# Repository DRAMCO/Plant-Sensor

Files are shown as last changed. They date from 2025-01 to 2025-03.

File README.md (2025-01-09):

# Plant Sensor

<p align="center">

</p>

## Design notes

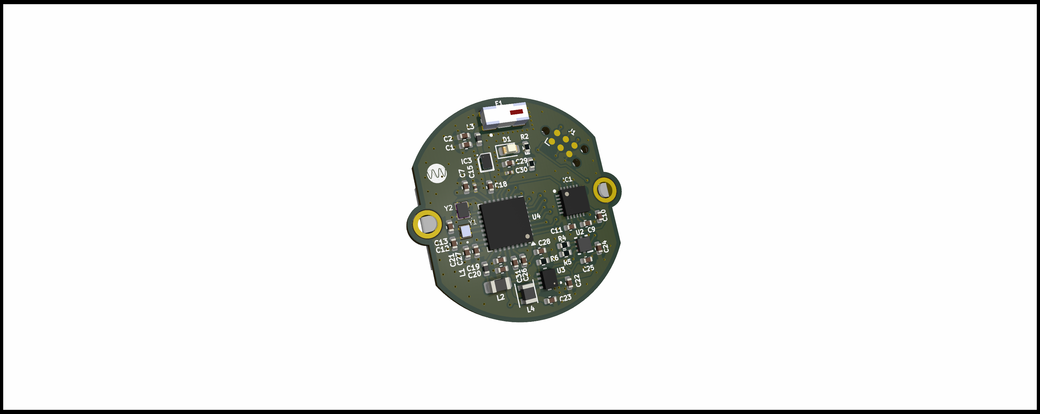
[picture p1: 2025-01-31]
V2/Hardware/Renders/plant_sensor_v2_front.png

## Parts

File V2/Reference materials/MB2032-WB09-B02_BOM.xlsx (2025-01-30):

 |  |  | Bill of materials
 |  |  | Board reference: | MB2032
 |  |  | Variant: | WB09
 |  |  | PCB revision: | B
 |  |  | Assembly revision: | 02
 |  |  | Date: | 6/21/2024
Designator | Description | Package | Manufacturer | Manufacturer_Part_Number | Fitted | Quantity
C2 | Capacitor, MLCC, 0.9pF, 50V, COG, +/-0.05pF, 0402, T=0.5mm | 0402 | MURATA | GJM1555C1HR90WB01 | Fitted | 1
C3, C6, C11, C12 | Capacitor, MLCC, 100nF, ±10%, X7R, 25V, 0402, T=0.5mm | 0402 | MURATA | GRM155R71E104KE14D | Fitted | 4
C4, C5 | Capacitor, C0G, 3 pF, 50V, NPO, ±0.1pF, 0402, T=0.5mm | 0402 | WALSIN TECHNOLOGY CORPORATION | 0402N3R0B500CT | Fitted | 2
C7 | Capacitor, MLCC, 20pF, 25V, COG, +/-2%, 0201, T=0.33mm | 0201 | MURATA | GJM0335C1E200GB01 | Fitted | 1
C8, C9 | Capacitor, MLCC, 10pF, 50V, NPO, +/-5%, 0402, T=0.5mm | 0402 | YAGEO | CC0402JRNPO9BN100 | Fitted | 2
C13 | Capacitor, MLCC, 1uF, X7R, 6.3V, 0402, ± 10%, T=0.5mm | 0402 | MURATA | GRM155R70J105KA12 | Fitted | 1
C14, C15 | Capacitor, MLCC, 4.7uF, X5R, 10 V, 0402, ± 20%, T=0.5mm | 0402 | MURATA | GRM155R61A475MEAAD | Fitted | 2
C16 | Capacitor, MLCC, 0.22uF, X5R, 6.3V, +/-10%, 0402, T=0.5mm | 0402 | YAGEO | CC0402KRX5R5BB224 | Fitted | 1
CN1, CN2 | Header, 25x2, 12.7mm, VR, SMD, T=4.83mm |  | SAMTEC | FTSH-125-02-L-DV | Fitted | 2
HW1 | RFI shield can, 20x15x3mm | 20x15x3mm | HARWIN | S02-20150300 | Fitted | 1
JP1 | Header, 3x1, 2.54mm, VR, TH, T=5.84mm/2.54mm |  | SAMTEC | TSW-103-07-F-S | Fitted | 1
L2 | Inductor, MLCC, 22nH, ±2%, 350mA, 0.58R, 0402, T=1.45mm | 0402 | MURATA | LQG15HN22NG02D | Fitted | 1
L3 | Inductor, MLCC, 10uH, ±20%, 300mA, 845mR, 0805, T=1.45mm | 0805 | MURATA | LQM21DN100M70L | Fitted | 1
R1, R10 | Resistor, 0R, 0402, +/-5%, 1/16W | 0402 | YAGEO | RC0402JR-070RL | Fitted | 2
R3 | Resistor, 100K, 0402, +/-1%, 1/16W | 0402 | YAGEO | RC0402FR-07100KL | Fitted | 1
SB6, SB7, SB9, SB11, SB14, SB16, SB17, SB20, SB28, SB32, SB34, SB37, SB38, SB41, SB43, SB47, SB48, SB55, SB57 | Solder Bridge 0402 ON | 0402 | YAGEO | RC0402JR-070RL | Fitted | 19
SC1, SC2, SC7, SC8 | shield clip Harwin S0981-46R to fix RF shielded cavity - SMT RFI Shield Clip, Corner (T+R) | 0.8x4.7x1.4mm | HARWIN | S0981-46R | Fitted | 4
SC3, SC4, SC5, SC6 | shield clip Harwin S0951-46R to fix RF shielded cavity | 1.1x3.9mm | HARWIN | S0951-46R | Fitted | 4
U1 | Bluetooth® Low Energy wireless SoC | QFN32 | STMICROELECTRONICS | STM32WB09KEV6TR | Fitted | 1
U2 | 2.4 GHz low pass filter matched to BLUENRG-LP-LPS | CSP6 | STMICROELECTRONICS | MLPF-NRG-01D3 | Fitted | 1
X1 | Crystal, 32MHz, 8pF, +/-10ppm, 60R, 2x1.6mm | 2x1.6mm | NDK | NX2016SA-32MHZ-EXS00A-CS06654 | Fitted | 1
X2 | Crystal, 32.768kHz, 7pF, +/-20ppm, 80K, 2.05x1.2mm | 2.05x1.2mm | NDK | NX2012SA-32.768KHZ-EXS00A-MU00389 | Fitted | 1
C1 | Capacitor, MLCC, 6.8pF, 50V, C0G, +/-0.05pF, 0402, T=0.5mm | 0402 | MURATA | GJM1555C1H6R8WB01 | Not Fitted | 0
C10 | Capacitor, MLCC, 100nF, ±10%, X7R, 25V, 0402, T=0.5mm | 0402 | MURATA | GRM155R71E104KE14D | Not Fitted | 0
CN3 | Header, 7x2, 1.27mm, VR, T=5.97mm, FTSH series STDC14 without Alignment Pin |  | SAMTEC | FTSH-107-01-L-DV-K | Not Fitted | 0
CN4 | Connector_RF, 0Hz to 6GHz, 50R, VR, SMD, T= 1.25mm |  | HIROSE | U.FL-R-SMT-1 | Not Fitted | 0
R2 | Resistor, 0R, 0402, +/-5%, 1/16W | 0402 | YAGEO | RC0402JR-070RL | Not Fitted | 0
R4, R5, R6, R7, R8 | Resistor, 47R, 0402, +/-1%, 1/16W | 0402 | YAGEO | RC0402FR-0747RL | Not Fitted | 0
R9 | Resistor, 100R, 0402, +/- 1%, 1/16W | 0402 | YAGEO | RC0402FR-07100RL | Not Fitted | 0
SB1, SB2, SB3, SB4, SB5, SB8, SB10, SB12, SB13, SB15, SB18, SB19, SB21, SB22, SB23, SB24, SB25, SB29, SB30, SB31, SB33, SB35, SB36, SB39, SB40, SB42, SB44, SB45, SB46, SB49, SB51, SB52, SB53, SB54, SB56 | Solder Bridge 0402 ON | 0402 | YAGEO | RC0402JR-070RL | Not Fitted | 0

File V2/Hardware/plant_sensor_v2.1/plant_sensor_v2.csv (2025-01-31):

Id | Designator | Footprint | Quantity | Designation | Supplier and ref
1 | C23 | C_0402_1005Metric | 1 | 10u
2 | J1 | Tag-Connect_TC2030-IDC-NL_2x03_P1.27mm_Vertical | 1 | TC2030_SWD-MCP-NL
3 | E1 | XDCR_2450AT42E0100E | 1 | 609-2450AT42E0100001
4 | C27,C25,C24,C9,C10,C7,C19,C26,C11,C29 | C_0402_1005Metric | 10 | 100n
5 | C31 | C_0402_1005Metric | 1 | 220n
6 | C1,C2 | C_0402_1005Metric | 2 | DNP
7 | U2 | RSE0008A | 1 | TPS22960RSER
8 | C21,C20,C22 | C_0402_1005Metric | 3 | 4.7u
9 | D1 | LED_0603_1608Metric | 1 | LED, RED
10 | L3 | L_0402_1005Metric | 1 | DNP
11 | TP10,TP1,TP8,TP2,TP4,TP5,TP11,TP9,TP6,TP7 | TestPoint_Pad_D1.0mm | 10 | TestPoint
12 | L2 | L_0805_2012Metric | 1 | LQM21DN100M70L - 10u
13 | C28 | C_0402_1005Metric | 1 | 1u
14 | R4 | R_0402_1005Metric | 1 | 470k
15 | U3 | VSON8_2P1X1P6_TEX | 1 | TPS62840DLCR
16 | R6 | R_0402_1005Metric | 1 | 0
17 | L4 | L_Murata_DFE201610P | 1 | 81-DFE201612E-2R2MP2 - 2u2
18 | R2 | R_0402_1005Metric | 1 | R
19 | Y1 | XTAL_ECS-.327-6-1210-TR | 1 | 520-.327-6-1210-TR (32.768kHz)
20 | C15,C30 | C_0201_0603Metric | 2 | 3p
21 | L1 | L_0402_1005Metric | 1 | LQG15HN22NG02D - 22n
22 | Y2 | OSCSC105P160X120X35-4N | 1 | NX1612SA-32.000MHZ-CHP-CIS-3
23 | IC1 | ICM20948 | 1 | ICM-20948
24 | C12,C13 | C_0402_1005Metric | 2 | 6p
25 | C18 | C_0402_1005Metric | 1 | 20p
26 | R5 | R_0402_1005Metric | 1 | 220k
27 | R3 | R_0402_1005Metric | 1 | 100k
28 | IC3 | MLPFNRG01D3 | 1 | MLPF-NRG-01D3
29 | U4 | QFN-32-1EP_5x5mm_P0.5mm_EP3.7x3.7mm | 1 | STM32WB09KEVx
30 | B1 | WA-BCMC_79523211 | 1 | WA-BCMC

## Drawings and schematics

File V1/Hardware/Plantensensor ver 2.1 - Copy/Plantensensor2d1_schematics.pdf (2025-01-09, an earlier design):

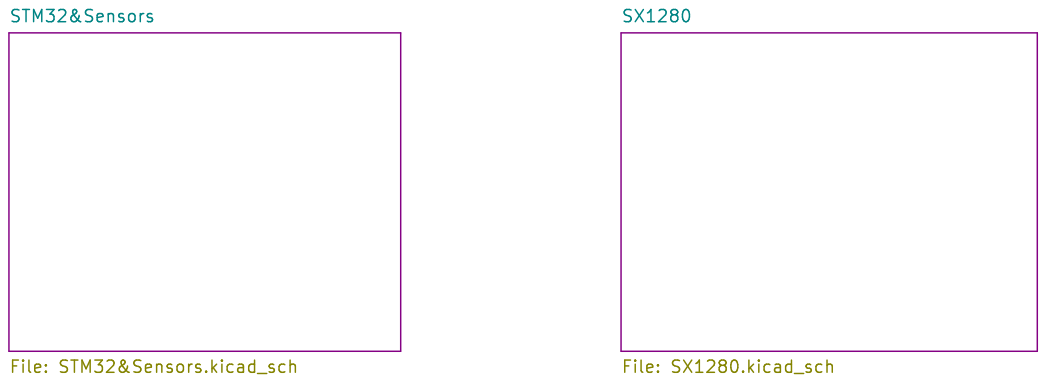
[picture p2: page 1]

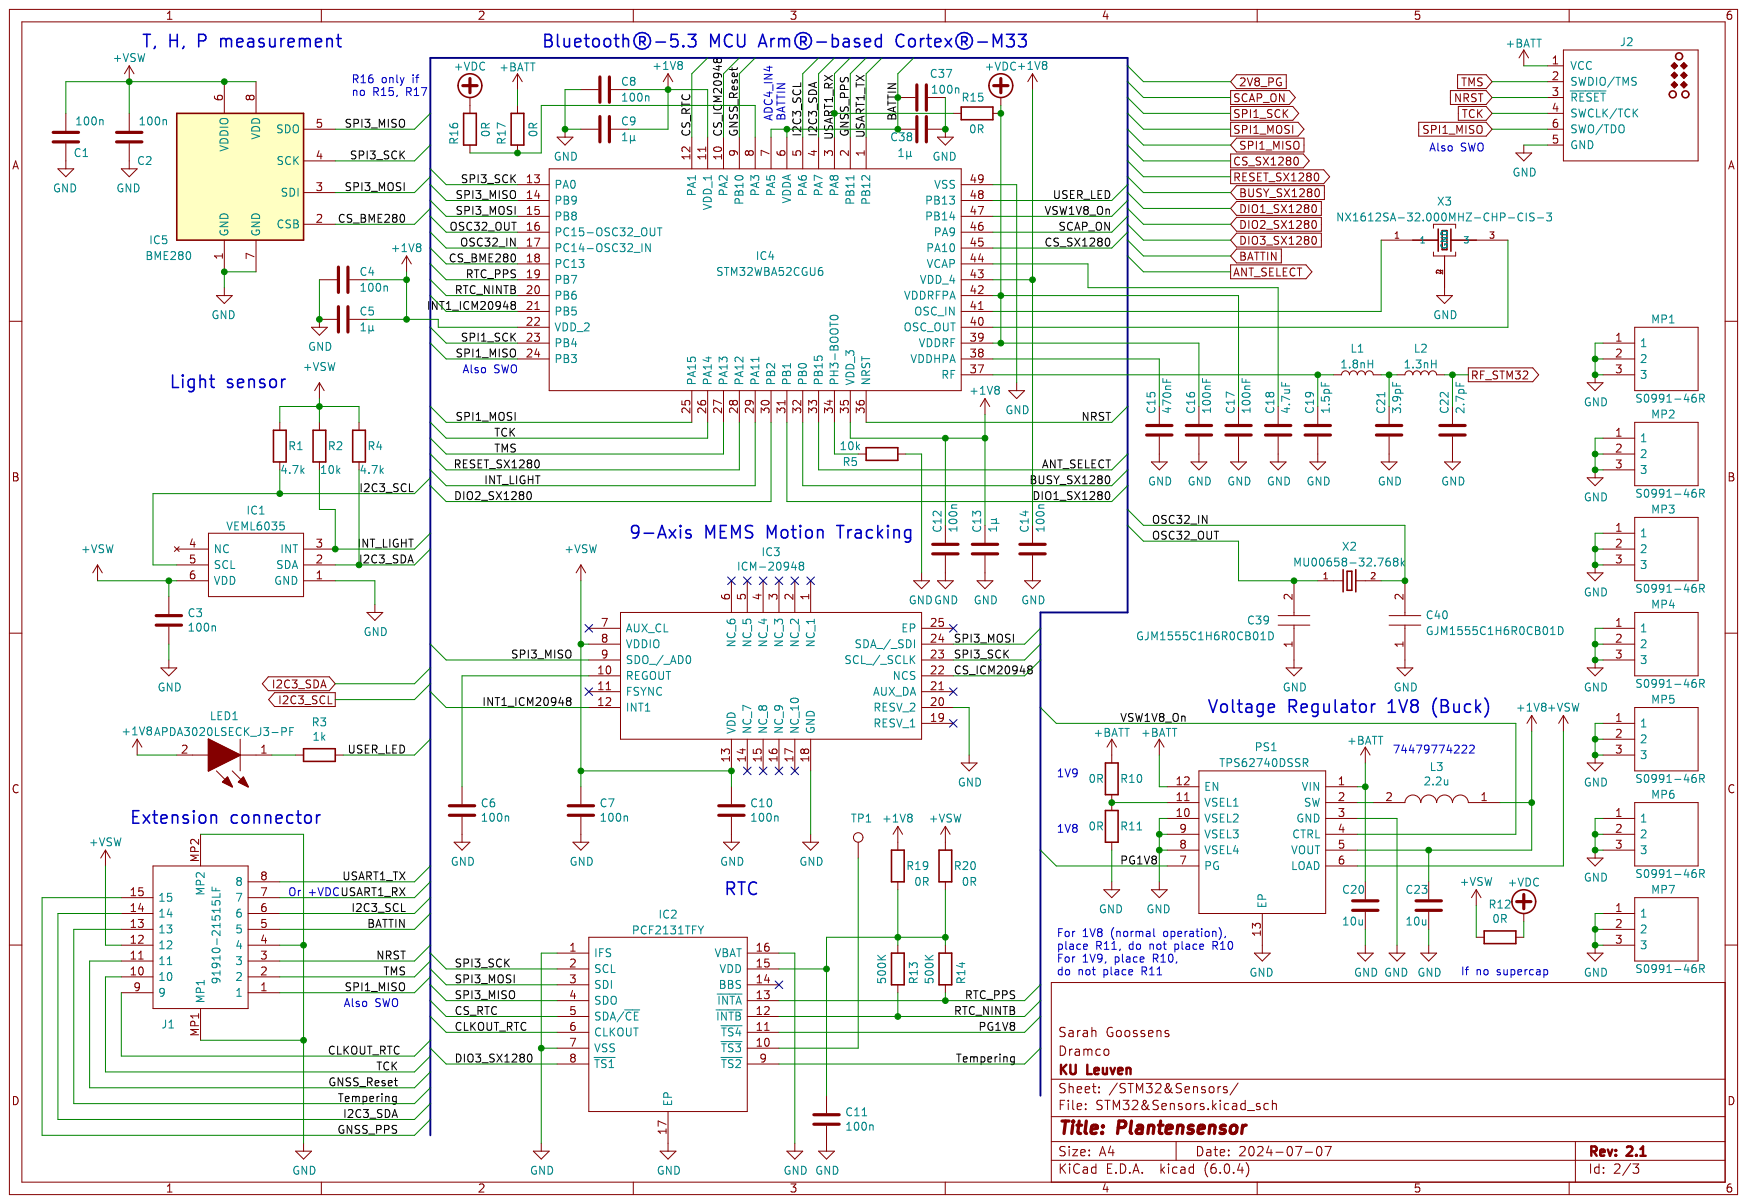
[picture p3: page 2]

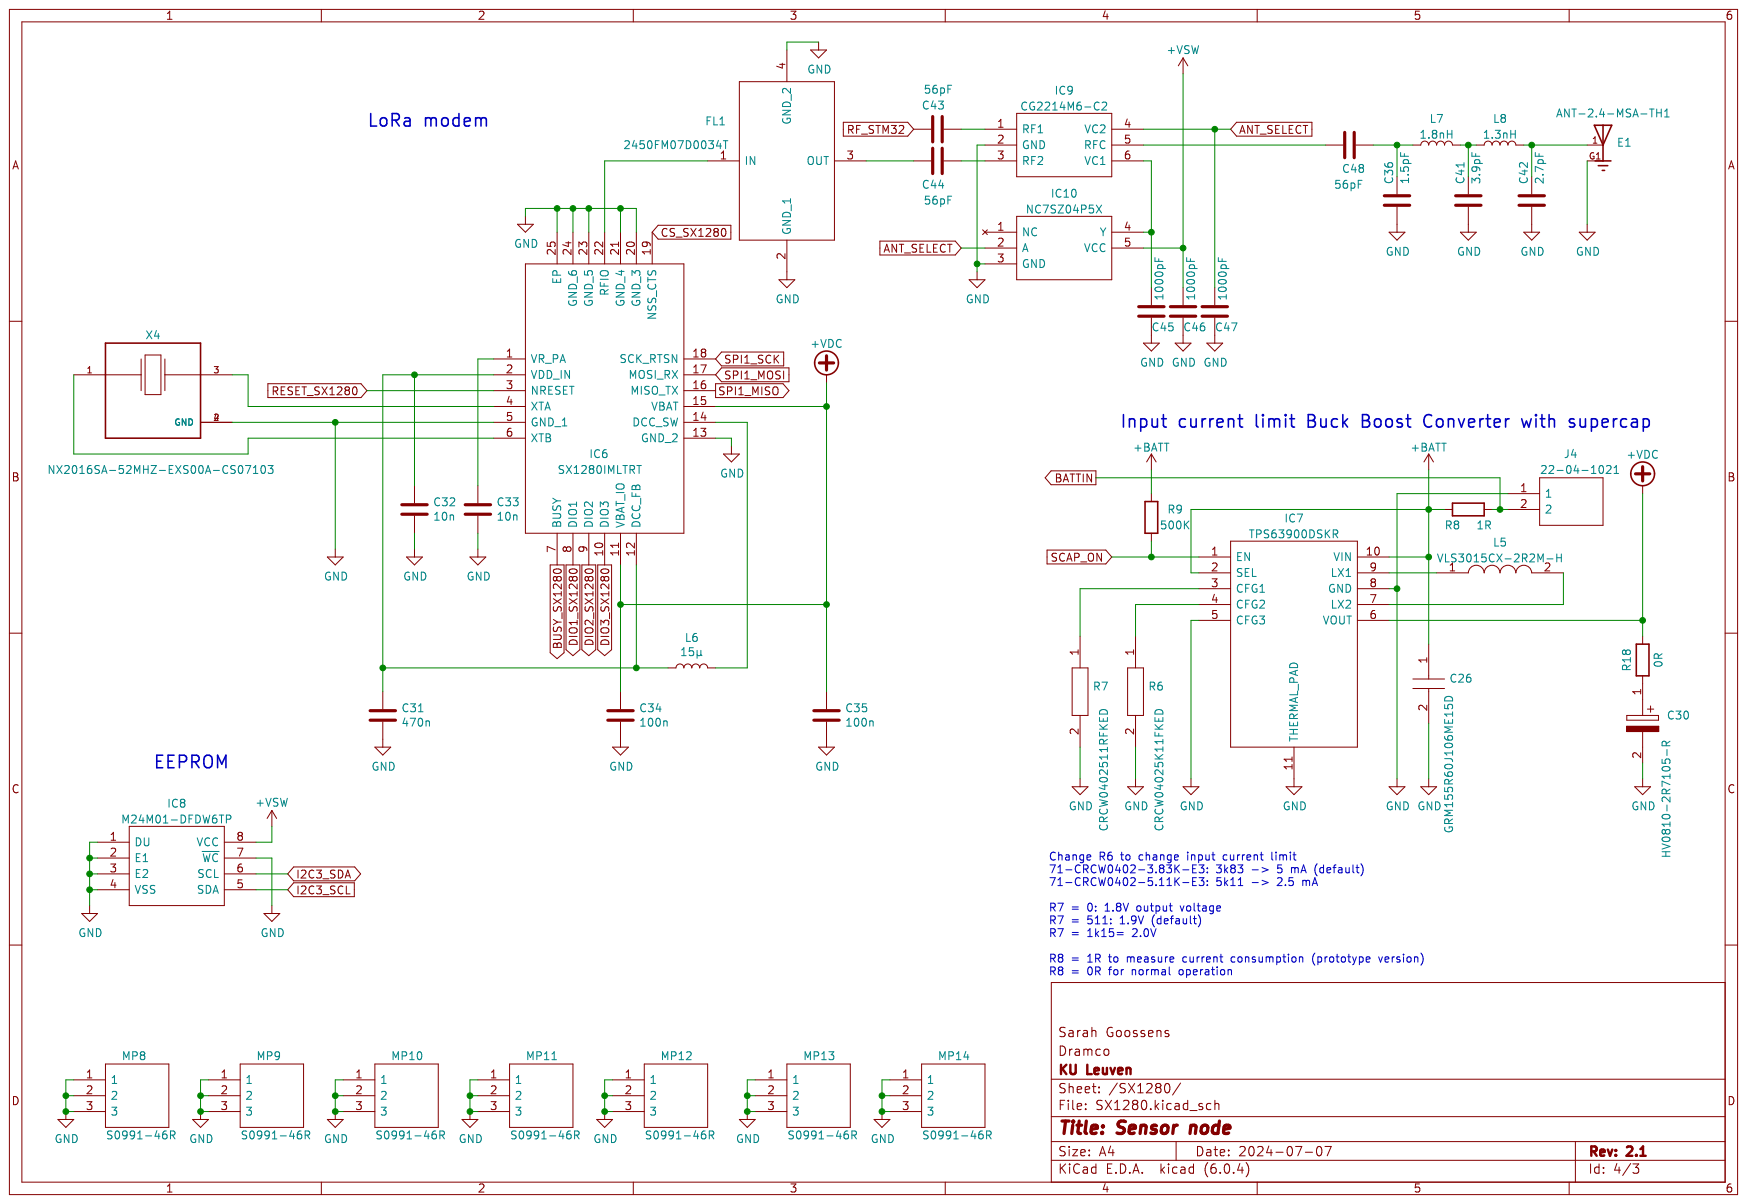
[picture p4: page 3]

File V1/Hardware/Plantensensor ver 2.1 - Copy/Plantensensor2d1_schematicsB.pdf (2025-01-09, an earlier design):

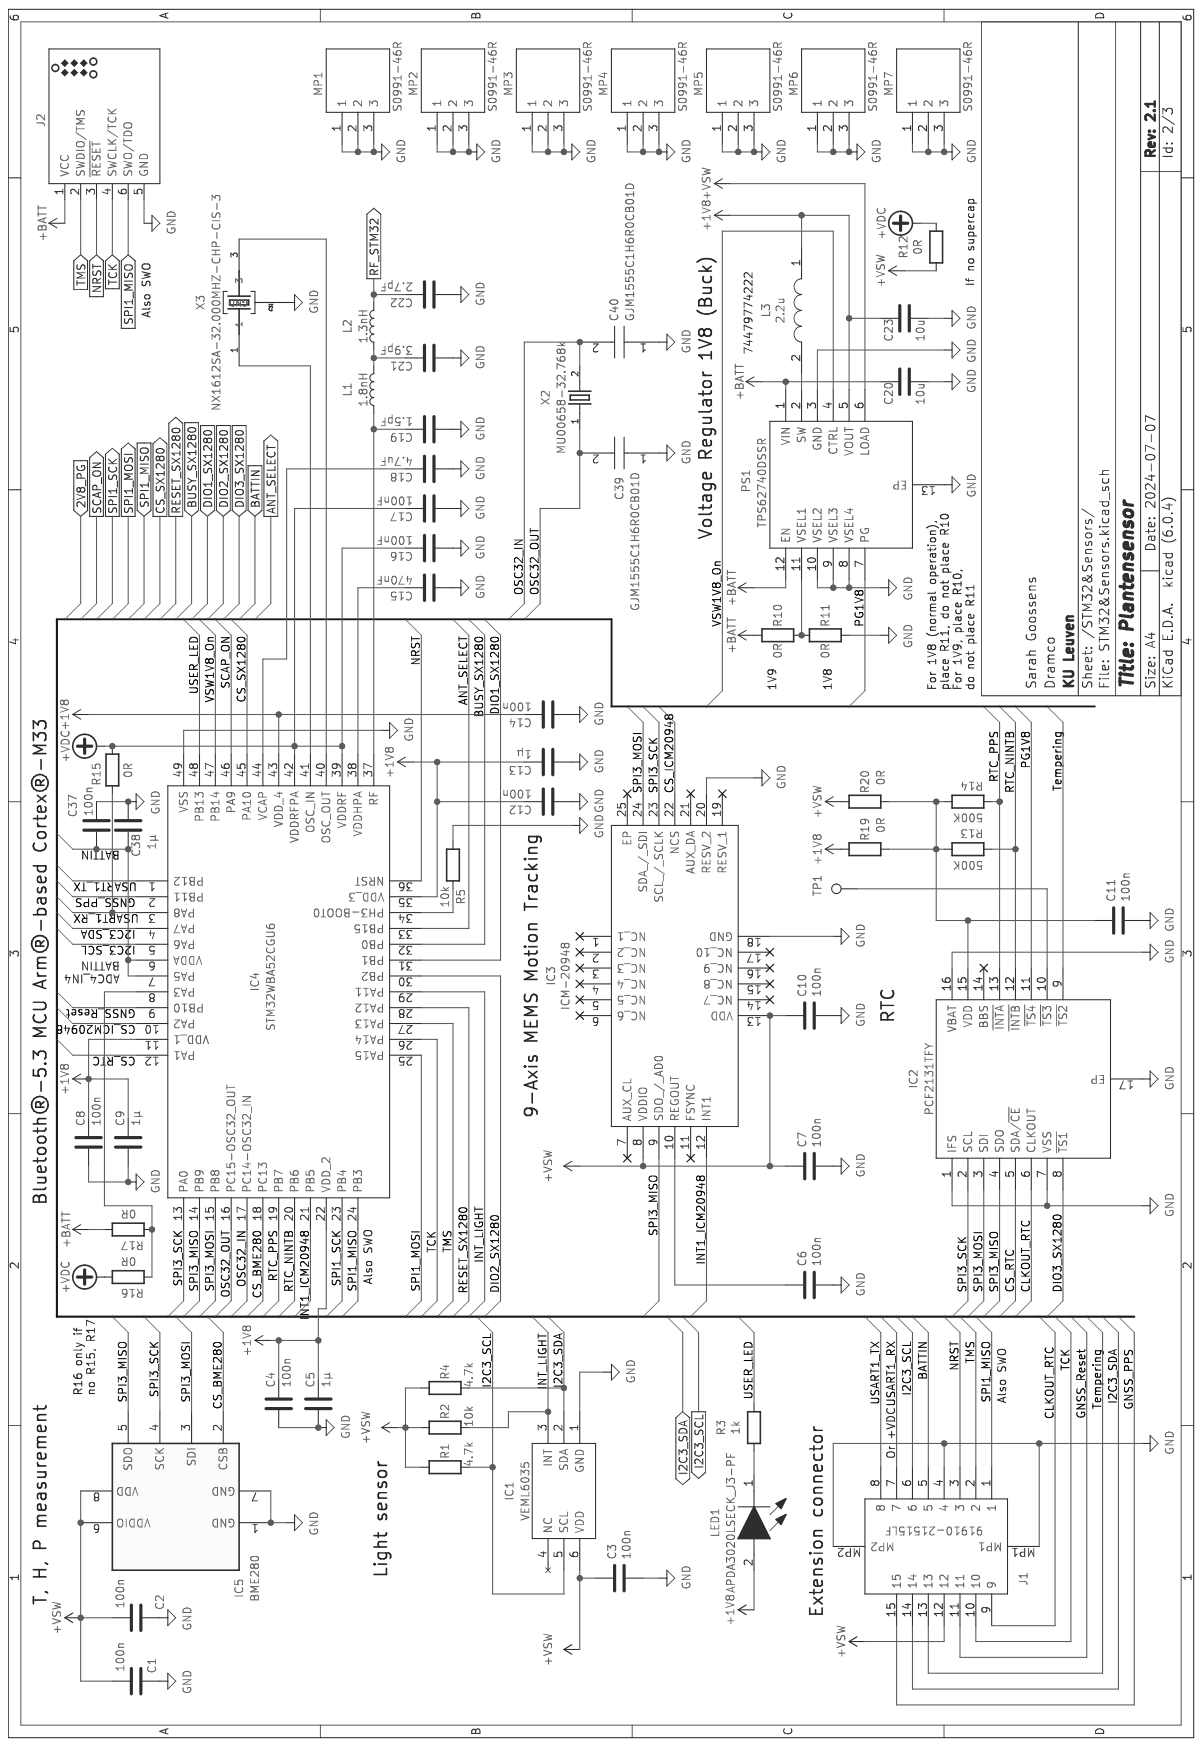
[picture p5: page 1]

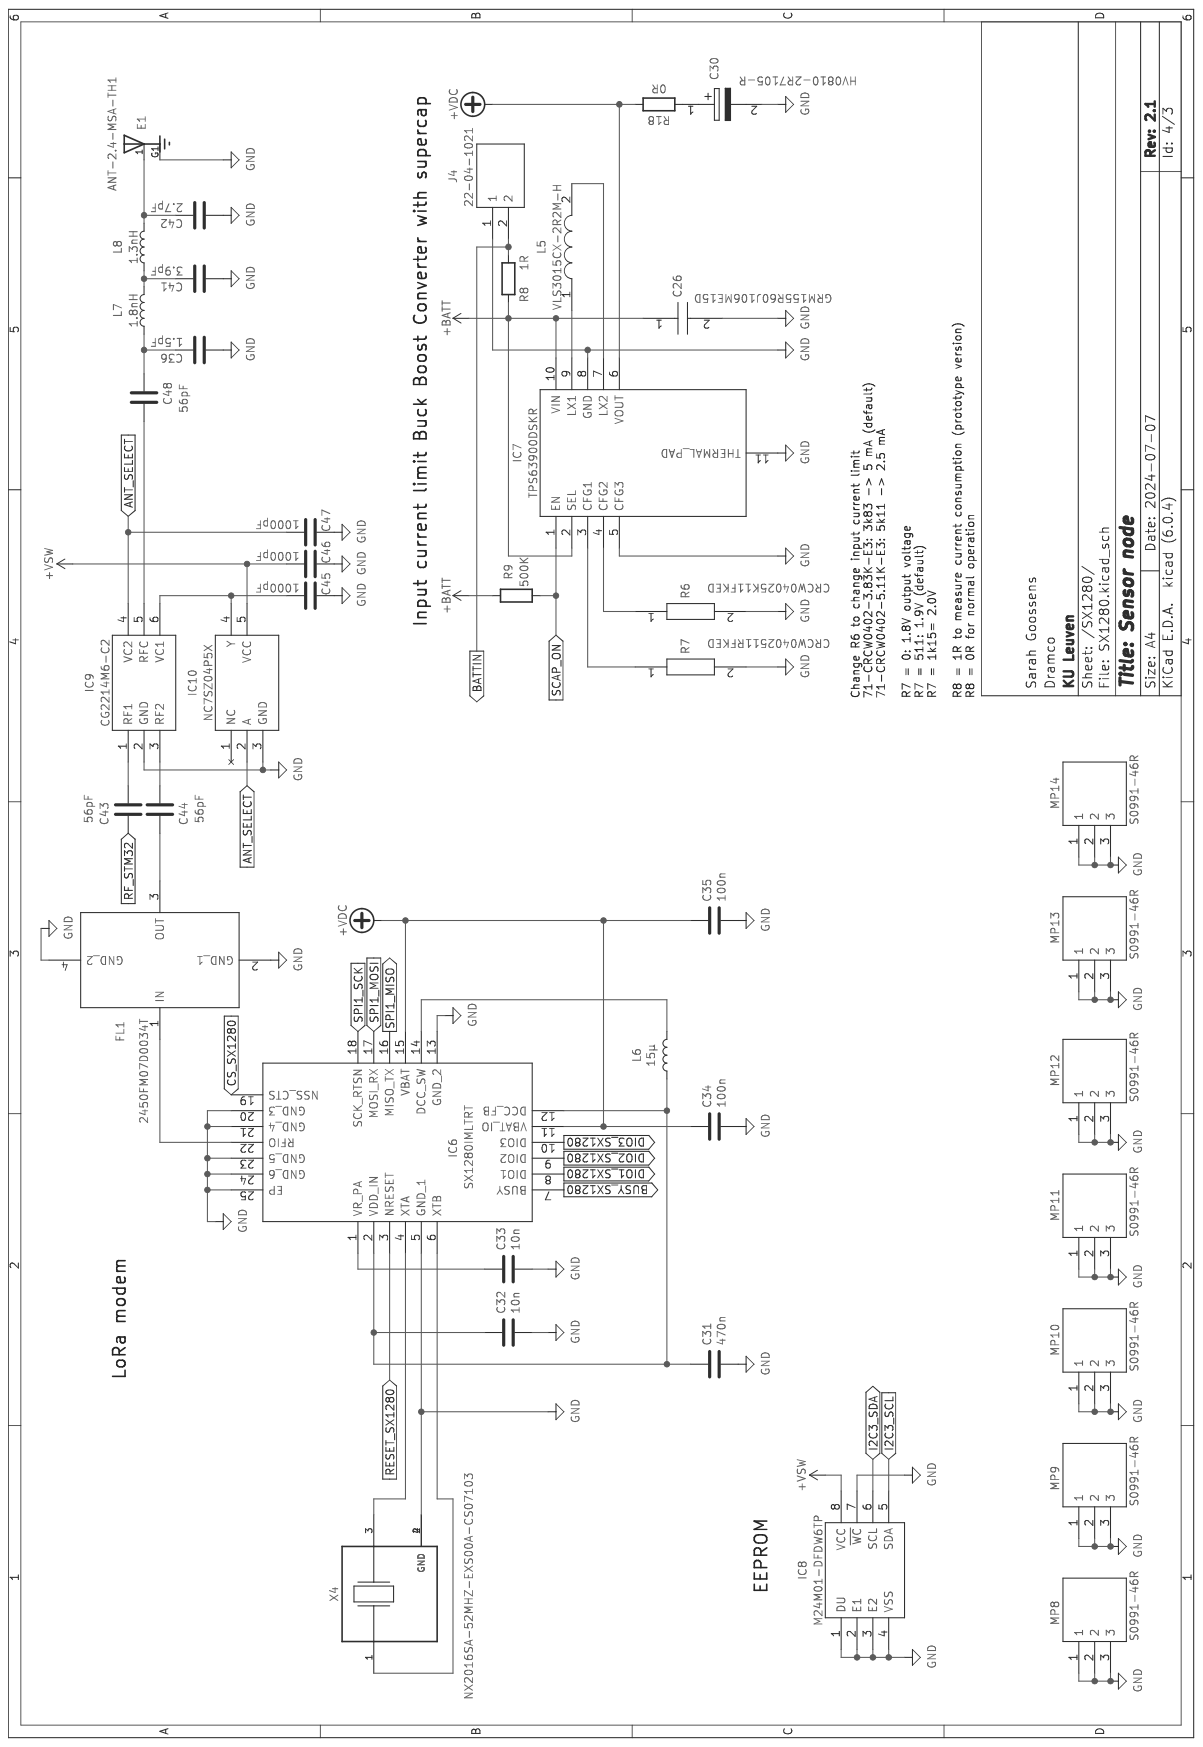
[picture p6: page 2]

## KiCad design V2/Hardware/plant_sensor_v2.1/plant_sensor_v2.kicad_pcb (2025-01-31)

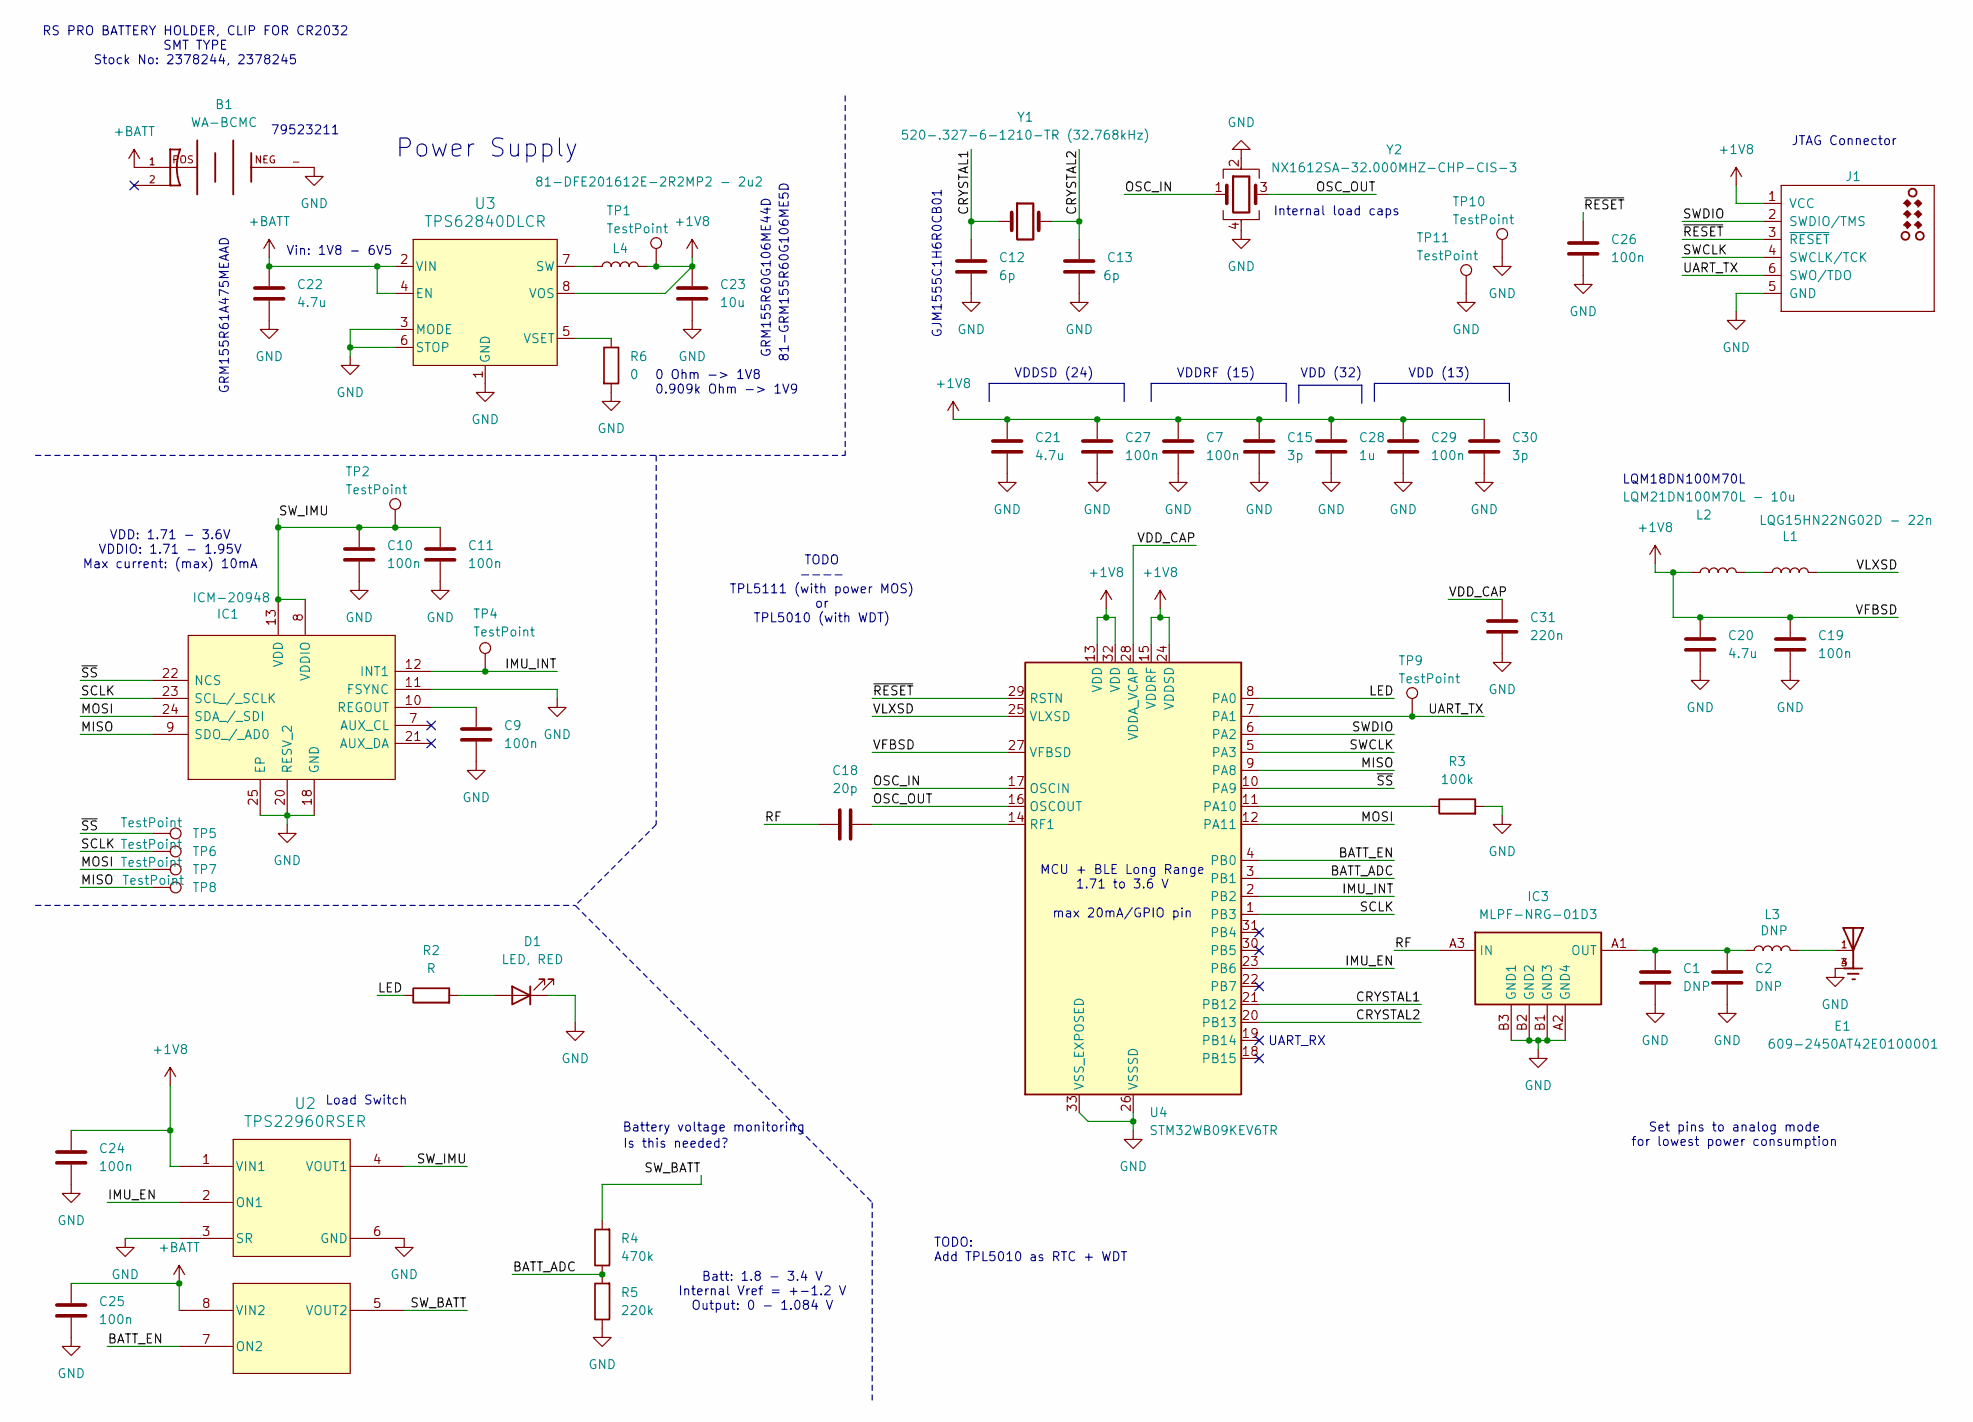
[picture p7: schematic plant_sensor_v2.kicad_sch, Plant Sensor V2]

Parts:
B1: WA-BCMC; WA-BCMC_79523211; PART-NUMBER 79523141
C1, C2: DNP; C_0402_1005Metric
C7, C9, C10, C11, C19, C24, C25, C26, C27, C29: 100n; C_0402_1005Metric
C12, C13: 6p; C_0402_1005Metric
C15, C30: 3p; C_0201_0603Metric
C18: 20p; C_0402_1005Metric
C20, C21, C22: 4.7u; C_0402_1005Metric
C23: 10u; C_0402_1005Metric
C28: 1u; C_0402_1005Metric
C31: 220n; C_0402_1005Metric
D1: LED, RED; LED_0603_1608Metric
E1: 609-2450AT42E0100001; XDCR_2450AT42E0100E; PARTREV 1.3
IC1: ICM-20948; ICM20948; Mouser Part Number 410-ICM-20948
IC3: MLPF-NRG-01D3; MLPFNRG01D3; Mouser Part Number 511-MLPF-NRG-01D3
J1: TC2030_SWD-MCP-NL; Tag-Connect_TC2030-IDC-NL_2x03_P1.27mm_Vertical
L1: LQG15HN22NG02D - 22n; L_0402_1005Metric
L2: LQM21DN100M70L - 10u; L_0805_2012Metric
L3: DNP; L_0402_1005Metric
L4: 81-DFE201612E-2R2MP2 - 2u2; L_Murata_DFE201610P
R2: R; R_0402_1005Metric
R3: 100k; R_0402_1005Metric
R4: 470k; R_0402_1005Metric
R5: 220k; R_0402_1005Metric
R6: 0; R_0402_1005Metric
TP1, TP2, TP4, TP5, TP6, TP7, TP8, TP9, TP10, TP11: TestPoint; TestPoint_Pad_D1.0mm
U2: TPS22960RSER; RSE0008A
U3: TPS62840DLCR; VSON8_2P1X1P6_TEX
U4: STM32WB09KEV6TR; QFN-32-1EP_5x5mm_P0.5mm_EP3.7x3.7mm
Y1: 520-.327-6-1210-TR (32.768kHz); XTAL_ECS-.327-6-1210-TR
Y2: NX1612SA-32.000MHZ-CHP-CIS-3; OSCSC105P160X120X35-4N

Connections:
+1V8: C7.1, C15.1, C19.1, C20.1, C21.1, C23.1, C24.1, C27.1, C28.1, C29.1, C30.1, J1.1 (VCC), L2.1, L4.2, TP1.1, U2.1 (VIN1), U3.8 (VOS), U4.13 (VDD), U4.15 (VDDRF), U4.24 (VDDSD), U4.27 (VFBSD), U4.32 (VDD)
+BATT: B1.1, C22.1, C25.1, U2.8 (VIN2), U3.2 (VIN), U3.4 (EN)
/BATT_ADC: R4.1, R5.2, U4.3 (PB1)
/BATT_EN: U2.7 (ON2), U4.4 (PB0)
/CRYSTAL1: C12.1, U4.21 (PB12), Y1.1
/CRYSTAL2: C13.1, U4.20 (PB13), Y1.2
/IMU_EN: U2.2 (ON1), U4.23 (PB6)
/IMU_INT: IC1.12 (INT1), TP4.1, U4.2 (PB2)
/LED: R2.1, U4.8 (PA0)
/MISO: IC1.9 (SDO_/_AD0), TP8.1, U4.9 (PA8)
/MOSI: IC1.24 (SDA_/_SDI), TP7.1, U4.12 (PA11)
/OSC_IN: U4.17 (OSCIN), Y2.1
/OSC_OUT: U4.16 (OSCOUT), Y2.3
/RF: C18.1, IC3.A3 (IN)
/SCLK: IC1.23 (SCL_/_SCLK), TP6.1, U4.1 (PB3)
/SWCLK: J1.4 (SWCLK/TCK), U4.5 (PA3)
/SWDIO: J1.2 (SWDIO/TMS), U4.6 (PA2)
/SW_BATT: R4.2, U2.5 (VOUT2)
/SW_IMU: C10.1, C11.1, IC1.8 (VDDIO), IC1.13 (VDD), TP2.1, U2.4 (VOUT1)
/UART_TX: J1.6 (SWO/TDO), TP9.1, U4.7 (PA1)
/VDD_CAP: C31.1, U4.28 (VDDA_VCAP)
/VLXSD: L1.2, U4.25 (VLXSD)
/~RESET: C26.2, J1.3 (~RESET), U4.29 (RSTN)
/~SS: IC1.22 (NCS), TP5.1, U4.10 (PA9)
GND: B1.-, C1.2, C2.2, C7.2, C9.2, C10.2, C11.2, C12.2, C13.2, C15.2, C19.2, C20.2, C21.2, C22.2, C23.2, C24.2, C25.2, C26.1, C27.2, C28.2, C29.2, C30.2, C31.2, D1.1 (K), E1.3, E1.4, IC1.11 (FSYNC), IC1.18 (GND), IC1.20 (RESV_2), IC1.25 (EP), IC3.A2 (GND4), IC3.B1 (GND3), IC3.B2 (GND2), IC3.B3 (GND1), J1.5 (GND), R3.2, R5.1, R6.2, TP10.1, TP11.1, U2.3 (SR), U2.6 (GND), U3.1 (GND), U3.3 (MODE), U3.6 (STOP), U4.26 (VSSSD), U4.33 (VSS_EXPOSED), Y2.2, Y2.4
unnamed: D1.2 (A), R2.2
unnamed: E1.1, L3.2
unnamed: C9.1, IC1.10 (REGOUT)
unnamed: C1.1, C2.1, IC3.A1 (OUT), L3.1
unnamed: L1.1, L2.2
unnamed: L4.1, U3.7 (SW)
unnamed: R6.1, U3.5 (VSET)
unnamed: R3.1, U4.11 (PA10)
unnamed: C18.2, U4.14 (RF1)

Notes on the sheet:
UART_RX
MCU + BLE Long Range 1.71 to 3.6 V max 20mA/GPIO pin
79523211
Vin: 1V8 - 6V5
Internal load caps
GRM155R60G106ME44D
Power Supply
RS PRO BATTERY HOLDER, CLIP FOR CR2032 SMT TYPE Stock No: 2378244, 2378245
GRM155R61A475MEAAD
VDD (32)
Battery voltage monitoring
JTAG Connector
Load Switch
Is this needed?
LQM18DN100M70L
Set pins to analog mode for lowest power consumption
VDD: 1.71 - 3.6V VDDIO: 1.71 - 1.95V Max current: (max) 10mA
VDD (13)
Batt: 1.8 - 3.4 V Internal Vref = +-1.2 V Output: 0 - 1.084 V
0 Ohm -> 1V8 0.909k Ohm -> 1V9
VDDSD (24)
TODO ---- TPL5111 (with power MOS) or TPL5010 (with WDT)
TODO: Add TPL5010 as RTC + WDT
VDDRF (15)
81-GRM155R60G106ME5D
GJM1555C1H6R0CB01

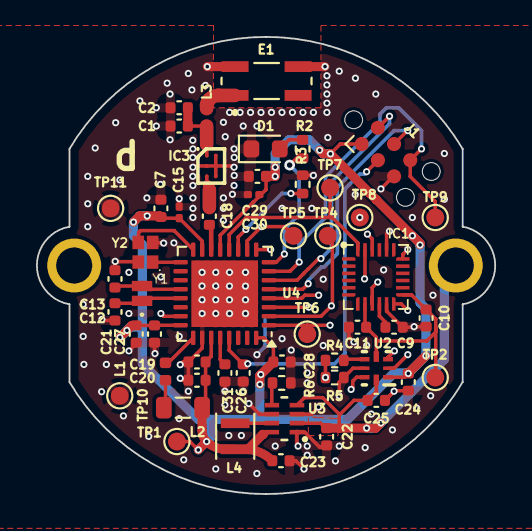
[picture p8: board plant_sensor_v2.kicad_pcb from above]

Board: 4 copper layers, 25.5 x 25.4 mm, 53 parts (1 on the bottom side), 34 nets.

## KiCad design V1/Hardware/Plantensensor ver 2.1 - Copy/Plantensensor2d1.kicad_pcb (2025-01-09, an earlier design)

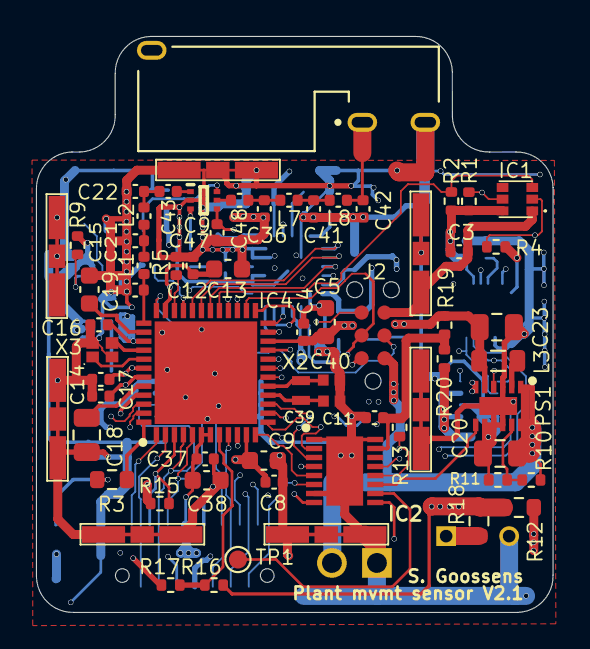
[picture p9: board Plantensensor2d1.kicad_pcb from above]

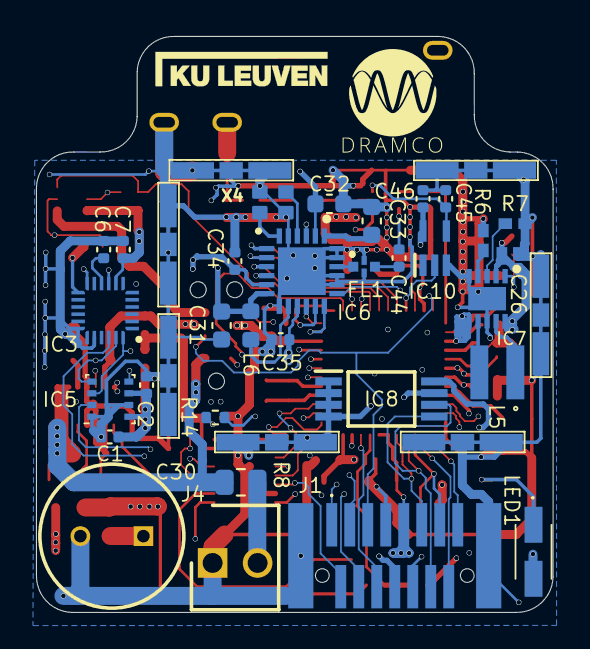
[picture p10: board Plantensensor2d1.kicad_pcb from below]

Board: 4 copper layers, 28.7 x 32.0 mm, 104 parts (38 on the bottom side), 77 nets.

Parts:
C1, C2, C3, C4, C6, C7, C8, C11, C12, C14, C34, C35, C37: 100n; C_0402_1005Metric
C5, C9, C13, C38: 1µ; C_0603_1608Metric
C15: 470nF; C_0603_1608Metric
C16, C17: 100nF; C_0402_1005Metric
C18: 4.7uF; C_0805_2012Metric
C19, C36: 1.5pF; C_0402_1005Metric
C20, C23: 10u; C_0805_2012Metric
C21, C41: 3.9pF; C_0402_1005Metric
C22, C42: 2.7pF; C_0402_1005Metric
C26: GRM155R60J106ME15D; CAPC1005X55N
C30: HV0810-2R7105-R; CAPPRD350W52D800H1350
C31: 470n; C_0603_1608Metric
C32, C33: 10n; C_0603_1608Metric
C39, C40: GJM1555C1H6R0CB01D; CAPC1005X55N
C43, C44, C48: 56pF; C_0402_1005Metric
C45, C46, C47: 1000pF; C_0402_1005Metric
E1: ANT-2.4-MSA-TH1; XCVR_ANT-2.4-MSA-TH1
FL1: 2450FM07D0034T
IC1: VEML6035
IC2: PCF2131TFY; SON50P350X450X150-17N-D_PCF2131TFY
IC3: ICM-20948; QFN40P300X300X105-25N-D_ICM20948
IC4: STM32WBA52CGU6; QFN50P700X700X65-49N-D
IC5: BME280; Bosch_LGA-8_2.5x2.5mm_P0.65mm_ClockwisePinNumbering
IC6: SX1280IMLTRT; QFN50P400X400X100-25N-D_SX1280
IC7: TPS63900DSKR; SON50P250X250X80-11N-D
IC8: M24M01-DFDW6TP; SOP65P640X120-8N
IC9: CG2214M6-C2; SOTFL48P130X55-6N
IC10: NC7SZ04P5X; SOT65P210X110-5N
J1: 91910-21515LF; 9191021515LF
J2: TC2030_SWD-MCP-NL; TC2030-MCP-NL
J4: 22-04-1021; SHDR2W64P0X250_1X2_450X580X1170P
L1, L7: 1.8nH; C_0402_1005Metric
L2, L8: 1.3nH; C_0402_1005Metric
L3: 2.2u; L_0805_2012Metric
L5: VLS3015CX-2R2M-H; VLS3015
L6: 15µ; L_0603_1608Metric
LED1: APDA3020LSECK_J3-PF; APDA3020LSECKJ3PF
MP1, MP2, MP3, MP4, MP5, MP6, MP7, MP8, MP9, MP10, MP11, MP12, MP13, MP14: S0991-46R; S099146R
PS1: TPS62740DSSR; SON50P200X300X80-13N_TPS62740DSSR
R1, R4: 4.7k; R_0402_1005Metric
R2, R5: 10k; R_0402_1005Metric
R3: 1k; R_0603_1608Metric
R6: CRCW04025K11FKED; RESC1005X40N
R7: CRCW0402511RFKED; RESC1005X40N
R8: 1R; R_0805_2012Metric
R9, R13, R14: 500K; R_0402_1005Metric
R10, R11, R15, R16, R17, R19, R20: 0R; R_0402_1005Metric
R12, R18: 0R; R_0603_1608Metric
TP1: TestPoint; TestPoint_Pad_D1.0mm
X2: MU00658-32.768k; XTAL_ECS-.327-12.5-16-TR
X3: NX1612SA-32.000MHZ-CHP-CIS-3; OSCSC105P160X120X35-4N
X4: NX2016SA-52MHZ-EXS00A-CS07103; OSCCC200X160X50N

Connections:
+1V8: C4.1, C5.1, C8.1, C9.1, C12.1, C13.1, C14.1, C23.1, IC4.11 (VDD_1), IC4.22 (VDD_2), IC4.35 (VDD_3), IC4.43 (VDD_4), L3.1, LED1.2, PS1.5 (VOUT), R19.1
+BATT: C20.1, C26.1, IC7.2 (SEL), IC7.10 (VIN), J2.1 (VCC), PS1.1 (VIN), PS1.12 (EN), R8.1, R9.2, R10.1, R17.2
+VDC: C16.1, C17.1, C34.1, C35.1, IC4.39 (VDDRF), IC4.42 (VDDRFPA), IC6.11 (VBAT_IO), IC6.15 (VBAT), IC7.6 (VOUT), R12.2, R15.2, R16.2, R18.2
+VSW: C1.1, C2.1, C3.1, C7.1, C46.2, IC1.6 (VDD), IC3.8 (VDDIO), IC3.13 (VDD), IC5.6 (VDDIO), IC5.8 (VDD), IC8.8 (VCC), IC10.5 (VCC), J1.12, PS1.6 (LOAD), R1.1, R2.1, R4.1, R12.1, R20.1
/STM32&Sensors/CLKOUT_RTC: IC2.6 (CLKOUT), J1.9
/STM32&Sensors/CS_BME280: IC4.18 (PC13), IC5.2 (CSB)
/STM32&Sensors/CS_ICM20948: IC3.22 (NCS), IC4.10 (PA2)
/STM32&Sensors/CS_RTC: IC2.5 (SDA/~CE), IC4.12 (PA1)
/STM32&Sensors/GNSS_PPS: IC4.2 (PB11), J1.15
/STM32&Sensors/GNSS_Reset: IC4.9 (PB10), J1.11
/STM32&Sensors/INT1_ICM20948: IC3.12 (INT1), IC4.21 (PB5)
/STM32&Sensors/INT_LIGHT: IC1.3 (INT), IC4.29 (PA11), R2.2
/STM32&Sensors/OSC32_IN: C40.2, IC4.17 (PC14-OSC32_IN), X2.2
/STM32&Sensors/OSC32_OUT: C39.2, IC4.16 (PC15-OSC32_OUT), X2.1
/STM32&Sensors/PG1V8: IC2.11 (~TS4), PS1.7 (PG)
/STM32&Sensors/RTC_NINTB: IC2.12 (~INTB), IC4.20 (PB6), R13.2
/STM32&Sensors/RTC_PPS: IC2.13 (~INTA), IC4.19 (PB7), R14.2
/STM32&Sensors/SPI3_MISO: IC2.4 (SDO), IC3.9 (SDO_/_AD0), IC4.14 (PB9), IC5.5 (SDO)
/STM32&Sensors/SPI3_MOSI: IC2.3 (SDI), IC3.24 (SDA_/_SDI), IC4.15 (PB8), IC5.3 (SDI)
/STM32&Sensors/SPI3_SCK: IC2.2 (SCL), IC3.23 (SCL_/_SCLK), IC4.13 (PA0), IC5.4 (SCK)
/STM32&Sensors/Tempering: IC2.9 (~TS2), J1.13
/STM32&Sensors/USART1_RX: IC4.3 (PA8), J1.7, R15.1
/STM32&Sensors/USART1_TX: IC4.1 (PB12), J1.8
/STM32&Sensors/USER_LED: IC4.48 (PB13), R3.2
/STM32&Sensors/VSW1V8_On: IC4.47 (PB14), PS1.4 (CTRL)
ANT_SELECT: C47.2, IC4.33 (PB15), IC9.4 (VC2), IC10.2 (A)
BATTIN: C37.1, C38.1, IC4.6 (VDDA), IC4.7 (PA5), J1.5, J4.2, R8.2
BUSY_SX1280: IC4.32 (PB0), IC6.7 (BUSY)
CS_SX1280: IC4.45 (PA10), IC6.19 (NSS_CTS)
DIO1_SX1280: IC4.31 (PB1), IC6.8 (DIO1)
DIO2_SX1280: IC4.30 (PB2), IC6.9 (DIO2)
DIO3_SX1280: IC2.8 (~TS1), IC6.10 (DIO3)
GND: C1.2, C2.2, C3.2, C4.2, C5.2, C6.2, C7.2, C8.2, C9.2, C11.2, C12.2, C13.2, C14.2, C15.2, C16.2, C17.2, C18.2, C19.2, C20.2, C21.2, C22.2, C23.2, C26.2, C30.2, C31.2, C32.2, C33.2, C34.2, C35.2, C36.2, C37.2, C38.2, C39.1, C40.1, C41.2, C42.2, C45.1, C46.1, C47.1, E1.G1, FL1.2 (GND_1), FL1.4 (GND_2), IC1.1 (GND), IC2.1 (IFS), IC2.7 (VSS), IC2.16 (VBAT), IC2.17 (EP), IC3.18 (GND), IC3.20 (RESV_2), IC4.49 (VSS), IC5.1 (GND), IC5.7 (GND), IC6.5 (GND_1), IC6.13 (GND_2), IC6.20 (GND_3), IC6.21 (GND_4), IC6.23 (GND_5), IC6.24 (GND_6), IC6.25 (EP), IC7.5 (CFG3), IC7.8 (GND), IC7.11 (THERMAL_PAD), IC8.1 (DU), IC8.2 (E1), IC8.3 (E2), IC8.4 (VSS), IC8.7 (~WC), IC9.2 (GND), IC10.3 (GND), J1.4, J1.MP1, J1.MP2, J2.5 (GND), J4.1, MP1.1, MP1.2, MP1.3, MP2.1, MP2.2, MP2.3, MP3.1, MP3.2, MP3.3, MP4.1, MP4.2, MP4.3, MP5.1, MP5.2, MP5.3, MP6.1, MP6.2, MP6.3, MP7.1, MP7.2, MP7.3, MP8.1, MP8.2, MP8.3, MP9.1, MP9.2, MP9.3, MP10.1, MP10.2, MP10.3, MP11.1, MP11.2, MP11.3, MP12.1, MP12.2, MP12.3, MP13.1, MP13.2, MP13.3, MP14.1, MP14.2, MP14.3, PS1.3 (GND), PS1.8 (VSEL4), PS1.9 (VSEL3), PS1.10 (VSEL2), PS1.13 (EP), R5.1, R6.2, R7.2, R11.2, X3.2 (GND), X3.4 (GND), X4.2 (GND), X4.4 (GND)
I2C3_SCL: IC1.5 (SCL), IC4.5 (PA6), IC8.5 (SDA), J1.6, R1.2
I2C3_SDA: IC1.2 (SDA), IC4.4 (PA7), IC8.6 (SCL), J1.14, R4.2
NRST: IC4.36 (NRST), J1.3, J2.3 (~RESET)
unnamed: C6.1, IC3.10 (REGOUT)
unnamed: C11.1, IC2.15 (VDD), R13.1, R14.1, R19.2, R20.2
unnamed: C15.1, IC4.38 (VDDHPA)
unnamed: C18.1, IC4.44 (VCAP)
unnamed: C19.1, IC4.37 (RF), L1.1
unnamed: C21.1, L1.2, L2.1
unnamed: C30.1, R18.1
unnamed: C31.1, C32.1, IC6.2 (VDD_IN), IC6.12 (DCC_FB), L6.1
unnamed: C33.1, IC6.1 (VR_PA)
unnamed: C36.1, C48.1, L7.1
unnamed: C41.1, L7.2, L8.1
unnamed: C42.1, E1.1, L8.2
unnamed: C43.2, IC9.1 (RF1)
unnamed: C44.1, FL1.3 (OUT)
unnamed: C44.2, IC9.3 (RF2)
unnamed: C45.2, IC9.6 (VC1), IC10.4 (Y)
unnamed: C48.2, IC9.5 (RFC)
unnamed: FL1.1 (IN), IC6.22 (RFIO)
unnamed: IC2.10 (~TS3), TP1.1
unnamed: IC4.8 (PA3), R16.1, R17.1
unnamed: IC4.34 (PH3-BOOT0), R5.2
unnamed: IC4.40 (OSC_OUT), X3.3
unnamed: IC4.41 (OSC_IN), X3.1
unnamed: IC6.4 (XTA), X4.3
unnamed: IC6.6 (XTB), X4.1
unnamed: IC6.14 (DCC_SW), L6.2
unnamed: IC7.3 (CFG1), R7.1
unnamed: IC7.4 (CFG2), R6.1
unnamed: IC7.7 (LX2), L5.2
unnamed: IC7.9 (LX1), L5.1
unnamed: L3.2, PS1.2 (SW)
unnamed: LED1.1, R3.1
unnamed: PS1.11 (VSEL1), R10.2, R11.1
RESET_SX1280: IC4.28 (PA12), IC6.3 (NRESET)
RF_STM32: C22.1, C43.1, L2.2
SCAP_ON: IC4.46 (PA9), IC7.1 (EN), R9.1
SPI1_MISO: IC4.24 (PB3), IC6.16 (MISO_TX), J1.1, J2.6 (SWO/TDO)
SPI1_MOSI: IC4.25 (PA15), IC6.17 (MOSI_RX)
SPI1_SCK: IC4.23 (PB4), IC6.18 (SCK_RTSN)
TCK: IC4.26 (PA14), J1.10, J2.4 (SWCLK/TCK)
TMS: IC4.27 (PA13), J1.2, J2.2 (SWDIO/TMS)

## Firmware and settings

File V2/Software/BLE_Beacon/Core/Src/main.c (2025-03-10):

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
/* Includes ------------------------------------------------------------------*/
#include "main.h"
#include "dma.h"
#include "memorymap.h"
#include "pka.h"
#include "radio.h"
#include "radio_timer.h"
#include "spi.h"
#include "tim.h"
#include "usart.h"
#include "gpio.h"


void SystemClock_Config(void);
void PeriphCommonClock_Config(void);
/* USER CODE BEGIN PFP */
static void function_TASK_LED( void );
/* USER CODE END PFP */

/**
  * @brief  The application entry point.
  * @retval int
  */
int main(void)
{

  /* MCU Configuration--------------------------------------------------------*/

  /* Reset of all peripherals, Initializes the Flash interface and the Systick. */
  HAL_Init();

  /* Configure the system clock */
  SystemClock_Config();

  /* Configure the peripherals common clocks */
  PeriphCommonClock_Config();

  /* USER CODE BEGIN SysInit */
  HAL_Delay(100);
  /* USER CODE END SysInit */

  /* Initialize all configured peripherals */
  MX_GPIO_Init();
  MX_DMA_Init();
  MX_RADIO_Init();
  MX_RADIO_TIMER_Init();
  MX_PKA_Init();
  MX_USART1_UART_Init();
  MX_SPI3_Init();
  MX_TIM16_Init();
  MX_TIM2_Init();
  /* USER CODE BEGIN 2 */
  SEGGER_RTT_ConfigUpBuffer(0, NULL, NULL, 0, SEGGER_RTT_MODE_NO_BLOCK_SKIP);

  HAL_GPIO_WritePin(SPI3_CS_GPIO_Port, SPI3_CS_Pin, GPIO_PIN_SET);

  HAL_TIM_Base_Start(&htim2);
  /* USER CODE END 2 */

  /* Init code for STM32_BLE */
  MX_APPE_Init(NULL);

  /* Infinite loop */
  /* USER CODE BEGIN WHILE */

  UTIL_SEQ_RegTask(1U << TASK_LED, UTIL_SEQ_RFU, function_TASK_LED);
  UTIL_SEQ_RegTask(1U << TASK_IMU, UTIL_SEQ_RFU, poll_icm20948);

  UTIL_SEQ_SetTask(1U << TASK_LED, CFG_SEQ_PRIO_LOW);

  HAL_GPIO_WritePin(BATT_EN_GPIO_Port, BATT_EN_Pin, GPIO_PIN_SET);
  HAL_GPIO_WritePin(IMU_EN_GPIO_Port, IMU_EN_Pin, GPIO_PIN_SET);

  HAL_Delay(100);

  ICM20948_Init();

  while (1)
  {
    /* USER CODE END WHILE */
    MX_APPE_Process();

    /* USER CODE BEGIN 3 */

  }
  /* USER CODE END 3 */
}

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
/* USER CODE BEGIN 4 */
/* task definition */
static void function_TASK_LED( void )
{
    HAL_GPIO_WritePin(LED_GPIO_Port, LED_Pin, GPIO_PIN_RESET);
}

/* USER CODE END 4 */
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


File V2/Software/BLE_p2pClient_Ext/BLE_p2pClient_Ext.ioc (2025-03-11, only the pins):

Mcu.UserName=STM32WB09KEVx
PA1.Signal=USART1_TX
PB0.Signal=USART1_RX
PB12.Signal=RCC_OSC32_OUT
PB13.Signal=RCC_OSC32_IN

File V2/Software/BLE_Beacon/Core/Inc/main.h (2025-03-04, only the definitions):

#define BATT_EN_Pin GPIO_PIN_0
#define BATT_EN_GPIO_Port GPIOB
#define LED_Pin GPIO_PIN_0
#define LED_GPIO_Port GPIOA
#define SPI3_CS_Pin GPIO_PIN_9
#define SPI3_CS_GPIO_Port GPIOA
#define IMU_INT_Pin GPIO_PIN_7
#define IMU_INT_GPIO_Port GPIOB
#define IMU_EN_Pin GPIO_PIN_6
#define IMU_EN_GPIO_Port GPIOB

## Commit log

2025-01-15 v2 start pcb design
    [20240719 BOM.xlsx, BOM_order_information.xlsx, Plantensensor2d1.csv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]
2025-01-15 hardware update
    [plant_sensor_v2.kicad_sch]
2025-01-16 update hardware
    [plant_sensor_v2.kicad_pcb, plant_sensor_v2.kicad_sch]
2025-01-30 Hardware design, almost finished
    [plant_sensor_v2.kicad_pcb, plant_sensor_v2.kicad_sch]
2025-01-31 Hardware V2 Finished
    [plant_sensor_v2.kicad_pcb, plant_sensor_v2.kicad_sch]
2025-02-12 Software BLE beacon in STM32IDE
2025-02-19 Software update - sequencer, LED, and Batt and IMU enable
2025-02-25 Increase TX power
2025-02-27 SPI (not working yet)
    [BLE_Beacon.ioc, ICM20948.c, ICM20948.h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]
2025-03-10 ICM20948 meas working via SPI
2025-03-11 hardware copy
    [plant_sensor_v2.csv, plant_sensor_v2.kicad_pcb, plant_sensor_v2.kicad_sch]

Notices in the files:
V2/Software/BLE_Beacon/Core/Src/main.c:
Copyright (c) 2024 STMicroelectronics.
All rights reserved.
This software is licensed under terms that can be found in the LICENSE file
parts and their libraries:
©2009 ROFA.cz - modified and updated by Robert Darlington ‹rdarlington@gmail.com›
